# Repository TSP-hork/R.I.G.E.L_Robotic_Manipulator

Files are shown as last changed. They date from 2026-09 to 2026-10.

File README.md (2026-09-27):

# RIGEL — Robotic Interchangeable General-purpose Extensible Linkage

This repository is dedicated to the development of **RIGEL**, a high-performance, open-source modular robotic manipulator designed around an interchangeable and extensible architecture.

The goal of RIGEL is to create a versatile robotic platform where mechanical, electronic, and functional modules can be reconfigured, replaced, and extended without redesigning the entire system.

## Modular... what?

"Modular robotic platform" might sound like a fancy way of saying "a robot made from a bunch of parts." And, well... that's basically the idea.

Building and controlling a robotic arm usually requires deep programming skills and a complex understanding of the entire system, making most designs rigid and difficult to modify.

**RIGEL is my attempt to make that easier.**

The idea is to build the robot from interchangeable and extensible modules, so parts can be replaced, added, or reconfigured without redesigning the entire system.

And no, this is not a toy for grabbing cubes.

## What does "not a toy" mean?

A toy can grab something. A toy can rotate. This robot is designed to be a true industrial tool. It's designed to be precise and powerful enough to mill its own parts from aluminum, to weld, or to perform any task you can imagine.

The core idea is simple: This project provides a blueprint for anyone with common tools (like a 3D printer) and dedication to build an instrument capable of creating almost anything.

## How "good" is this cheap thing?

You might be thinking: "Okay, so you're making a cheap little arm and believe it can compete with a true, big, metal one? That's nonsense." And you are half right. This robot can't mill hardened steel or titanium. But does it need to?

What we all really need are strong, precise parts. We can't 3D-print metal, but this robot is designed to be precise enough to **mill aluminum**. This means you can use the first plastic robot to create the parts for its much stronger, metal successor. Sounds more realistic now, doesn't it?

But what about the "brains"? I've got you covered there too. This robot is being designed to run its control loop at **50 kHz**. This means it can react to a command in **20 microseconds** - the time from your signal to a change in the motor's current. And yes, it will work with almost any motor you want.

## Nice to meet you

I bet this sounds interesting. I just want to say hello, and I'm glad to see you here. This project started on May 27, 2025, and my goal is to build the first working prototype by next summer.

Maybe I'll make it, maybe I won't, but we'll find that out together. For now, you can find me here every Saturday. Let's get started!

## 05.07.26 Update "After a year"

Yeah, looking back, I wasn't sure what I was getting into at the start. I honestly thought I'd just tinker for a month and drop it, but here we are. Let's see what we've achieved!

I have finished the mechanics (I'd say they are 99% done). I also developed a 1kW motor driver—you can grab the Gerbers and order the boards for yourself(please note the non-commercial license below! sry for that). I've tested it and it works great, though I will personally be running it at 200W for this robot. I also wrote the FOC algorithm to control the motors.

I'll be continuing this journey, and I might change the name of the project soon. I really was here almost every Saturday (well, maybe not every single one, but I tried!).

A huge thank you to the two guys who starred my repo—it means a lot! I will keep going, we can do this! <Have a good day!> :>

## ⚖️ License

This project uses a **Dual-Licensing** model to protect both the software and the hardware designs.

*   **Software / Firmware:** All source code in this repository is licensed under the **GNU General Public License v3.0 (GPLv3)**. See the `LICENSE` file in the root directory for details.
*   **Hardware Designs:** All hardware files (Gerbers, Schematics, BOM, Pick and Place files, and 3D CAD models) located in the hardware/cad directories are licensed under the **Creative Commons Attribution-NonCommercial 4.0 International (CC BY-NC 4.0)** license. See the `LICENSE_HARDWARE.md` file for details.

**What this means for you:**
You are completely free to use, modify, and build the software and hardware for your own personal, educational, or hobby projects. However, **you may not use the hardware files for commercial purposes** (e.g., you cannot mass-produce the PCBs to sell them) without explicit permission.

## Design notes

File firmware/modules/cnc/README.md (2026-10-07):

# CNC Coordinator Module ESP32-S3

Standalone firmware module for coordinating a 3-axis robotic peripheral, a spindle variable-frequency drive, and a coolant/lubrication pump system.

## Architecture Principles

1. **Hardware Decoupling:**
   * The `Drivers/` layer handles chip-specific registers and startup for the ESP32-S3.
   * The `Core/` layer is portable and hardware-agnostic. All machine protocols, packet framing, and parsing logic are written in pure C without register dependencies.
2. **Centralized Application State (`main.c`):**
   * The main super-loop and master state machine live directly inside `main.c`, serving as the single source of truth for machine coordination, safety interlocks, and sequencing.
3. **WebSerial:**
   * The operator interface is a standalone local Web application (`src/ui/index.html`) running in any browser communicating directly over native USB Type-C via the WebSerial API.

## Project Structure

modules/cnc/
│
├── Makefile                      # Root build and flash script
├── CMakeLists.txt                # Tooling config for LSP, IDEs, and linters
├── README.md                     # Project documentation and quick-start guide
│
├── docs/                         # Specifications and hardware documentation
│   ├── pinout.md                 # ESP32-S3 pin assignments (UART, RS485, relays, USB-JTAG)
│   └── protocol.md               # 3-axis robot serial wire-protocol specification
│
└── src/
    ├── main.c                    # System entry point, master state machine & super-loop
    │
    ├── Core/                     # Hardware-independent machine logic
    │   ├── command_parser/       # Host command stream decoder
    │   │   ├── command_parser.c  # Ring-buffer parser and G-code/CLI tokenizer
    │   │   └── command_parser.h  # Command definitions and parser interface
    │   │
    │   ├── pump/                 # Coolant and lubrication subsystem
    │   │   ├── pump.c            # Relay timing logic and pressure/flow monitoring
    │   │   └── pump.h            # Pump control interface and status queries
    │   │
    │   ├── robot_interface/      # 3-axis robot communication driver
    │   │   ├── robot_interface.c # Frame serialization, timeout tracking & ACK handling
    │   │   └── robot_interface.h # Robot dispatch API and motion state flags
    │   │
    │   └── vfd/                  # Spindle inverter driver and Modbus RTU
    │       ├── vfd.c             # Modbus state machine, frequency scaling & current polling
    │       └── vfd.h             # VFD run/stop interface and register maps
    │
    ├── Drivers/                  # Hardware layer for ESP32-S3 
    │   ├── include/
    │   │   ├── bsp.h             # Hardware contract: exposed HAL interface for Core/
    │   │   └── esp32s3_regs.h    # Physical register addresses and bitmasks (GPIO, UART, WDT)
    │   └── src/
    │       ├── startup.S         # Reset vector, stack pointer setup & .bss zeroing
    │       ├── bsp_system.c      # Disabling MWDT/SWD watchdogs and PLL clock configuration
    │       ├── bsp_gpio.c        # Direct register pin-level read/write operations
    │       ├── bsp_uart.c        # Non-blocking UART FIFO handling and ring buffers
    │       └── bsp_timer.c       # Hardware timer tick generator
    │
    ├── ld/                       # Linker scripts
    │   └── esp32s3.ld            # SRAM and Flash memory region mappings
    │
    └── ui/                       # Operator control interface
        └── index.html            # Standalone WebSerial dashboard (inlined HTML, CSS & JS)
---

## Directory & Subsystem Overview

### `src/main.c`
The central commander of the system. Initializes the BSP layer and runs the primary non-blocking super-loop:
* Polls incoming USB packets and forwards them to `command_parser`.
* Evaluates safety interlocks (e.g., forbidding axis movement if spindle RPM or pump flow is unconfirmed).
* Dispatches motion commands to `robot_interface`.
* Polls `vfd` status and drives the master state machine (`IDLE`, `RUNNING`, `ERROR`, `PAUSED`).

### `src/Core/`
* **`command_parser/`**: Consumes raw byte streams from the host interface and converts them into structured command payloads.
* **`pump/`**: Controls the coolant/lubrication relay, manages start-up priming delays, and monitors pressure/flow switches.
* **`robot_interface/`**: Formats motion commands into the wire protocol expected by the peripheral 3-axis robot, handling timeouts and `ACK`/`BUSY` responses.
* **`vfd/`**: Calculates Modbus RTU CRC16 checksums, issues spindle run/stop commands, sets target frequency, and polls operating current/load.

### `src/Drivers/`
Contains all low-level hardware routines for the ESP32-S3:
* **`Drivers/include/bsp.h`**: The boundary contract exposing safe, non-blocking hardware functions (`bsp_uart_send`, `bsp_gpio_set`, `bsp_millis`) to `Core/` and `main.c`.
* **Hardware Drivers**: Register-level implementations of clock trees, watchdog timer disable sequences, UART FIFO handling, and interrupt vectors.

### `src/ld/`
Contains the linker script defining internal SRAM boundaries, vector tables, and Flash mappings.

### `src/ui/`
Self-contained HTML/JavaScript application. Runs locally on the host machine without web servers or Node.js. Connects directly to the board's native USB-Serial port to provide manual jogging, spindle overrides, and telemetry graphs.

---

## Toolchain & Prerequisites

ESP32-S3 utilizes the dual-core Xtensa LX7 architecture. Compilation requires the standalone Xtensa toolchain and OpenOCD:

1. **Toolchain:** Download the standalone `xtensa-esp32s3-elf` GCC toolchain release from Espressif's crosstool-NG repository and add its `/bin` directory to your `PATH` or set `PREFIX` in the `Makefile`.
2. **OpenOCD & Make :**
   ```bash
   # Ubuntu / Debian
   sudo apt update
   sudo apt install openocd make

   # Arch Linux
   sudo pacman -S openocd make
   ```

## Quick Start

### 1. Build the Binary
```bash
make
```
Executes a unified build with Link-Time Optimization `-flto`. Artifacts are written to `build/`.

### 2. Flash via Native USB-JTAG
ESP32-S3 features an on-chip USB-Serial/JTAG controller directly on the Type-C port (GPIO19/GPIO20):
```bash
make flash
```

### 3. Clean Build Artifacts
```bash
make clean
```

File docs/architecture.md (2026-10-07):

## Architecture.md

# Architecture of the RIGEL Robotic Manipulator

## Table of Contents

- [1. Overview](#1-overview)
- [2. Core Concept](#2-core-concept)
- [3. System Architecture](#3-system-architecture)
  - [3.1 System Block Diagram](#31-system-block-diagram)
  - [3.2 Data Flow: Control Loop](#32-data-flow-control-loop)
  - [3.3 Power Distribution](#33-power-distribution)
- [4. Electronics Architecture](#4-electronics-architecture)
  - [4.1 Motherboard](#41-motherboard)
  - [4.2 MCU: STM32H7A3](#42-mcu-stm32h7a3)
  - [4.3 FPGA: Lattice ECP5 (LFE5U-45F)](#43-fpga-lattice-ecp5-lfe5u-45f)
  - [4.4 MCU ↔ FPGA Communication](#44-mcu--fpga-communication)
  - [4.5 Power Blade (Axis Channel)](#45-power-blade-axis-channel)
  - [4.6 Technologist Module](#46-technologist-module)
  - [4.7 Input Power Board](#47-input-power-board)
- [5. Firmware Architecture](#5-firmware-architecture)
  - [5.1 FPGA Modules](#51-fpga-modules)
  - [5.2 MCU Firmware](#52-mcu-firmware)
  - [5.3 Control Loop Timing](#53-control-loop-timing)
- [6. Mechanical Architecture](#6-mechanical-architecture)
  - [6.1 Kinematic Configuration](#61-kinematic-configuration)
  - [6.2 Slew Drive (Rotary Support)](#62-slew-drive-rotary-support)
  - [6.3 Cabin](#63-cabin)
  - [6.4 Shoulder Module](#64-shoulder-module)
  - [6.5 Backpack (Motor + Reducer Mount)](#65-backpack-motor--reducer-mount)
  - [6.6 Balanced Cycloidal Reducer](#66-balanced-cycloidal-reducer)
  - [6.7 Base](#67-base)
- [7. The Technologist Module: Design Philosophy](#7-the-technologist-module-design-philosophy)
- [8. Design Principles](#8-design-principles)
- [9. Target Specifications](#9-target-specifications)
- [10. Current Status and Roadmap](#10-current-status-and-roadmap)

---

## 1. Overview

The RIGEL Robotic Manipulator is a fast, precise,
and affordable robotic arm designed for simple assembly, easy operation,
and tool-agnostic deployment. It is built from four electronic subsystems:
an Input Power Board, a Motherboard, hot-swappable Power Blades, and a
hot-swappable Technologist Module.

The robot is designed so that any person with a 3D printer and basic tools
can build an instrument capable of precise spatial positioning — precise
enough to mill aluminum and manufacture parts for a stronger, metal version
of itself.

## 2. Core Concept

The central idea behind RIGEL is the separation of concerns:

- **The Robot** is a precision positioning tool. It moves a point in space
  from A to B. It is a black box with a simple API.
- **The Technologist Module** defines *what to do*. It controls the tool,
  sends high-level commands, and can be swapped in seconds.
- **The Power Blades** drive the motors. They are hot-swappable cards that
  plug into the motherboard via a standard PCIe physical connector.

This separation means that switching from milling to welding requires only
swapping the Technologist Module and the tool — not reprogramming the robot.

## 3. System Architecture

### 3.1 System Block Diagram

```
[PSU 8-60V] ──→ [Input Power Board*] ──→ [MOTHERBOARD]
                                              │
                 ┌────────────┬───────────────┼───────────────┬────────────┐
                 │            │               │               │            │
            [Blade 1]   [Blade 2]   ...  [Blade 6]   [Technologist Module]
                 │            │               │               │
           [Motor+Enc]  [Motor+Enc]     [Motor+Enc]      [Tool/End Effector]

Inside the Motherboard:
┌─────────────────────────────────────────────────────────────────────┐
│                                                                     │
│   [FPGA: Lattice ECP5] ←── data bus ──→ [MCU: STM32H7A3]          │
│        │                                      │                     │
│        ├─ PWM signals      → Blade PCIe slots  ├─ FOC algorithm     │
│        ├─ Encoder data     ← Blade PCIe slots  ├─ Inverse kinematics│
│        ├─ SPI (ADC data)   ← Blade PCIe slots  ├─ API ↔ Tech Module│
│        ├─ Hardware dead-time protection         ├─ State machine     │
│        └─ Hardware clock sync (for clustering)  └─ Trajectory plan  │
│                                                                     │
│   [PCIe x8 Slots × 6]              [PCIe Slot × 1: Tech Module]   │
│                                                                     │
└─────────────────────────────────────────────────────────────────────┘

* Input Power Board is not implemented in the prototype.
  The prototype is powered directly from a 24V PSU.
```

### 3.2 Data Flow: Control Loop

Every control cycle (target: 20 µs / 50 kHz):

```
Step 1: FPGA triggers ADC conversion on the Blade
            │
Step 2: STM32G431 (on Blade) samples 3 phase currents
            │
Step 3: ADC data is sent via SPI to the FPGA          ← ~400 ns
            │
Step 4: FPGA decodes quadrature encoders (parallel)   ← 1-2 clock cycles
            │
Step 5: FPGA writes currents + positions directly
        into MCU registers (via data bus)              ← no CPU overhead
            │
Step 6: MCU (STM32H7) executes:
        - Clarke/Park transforms
        - PID current regulators (FOC)
        - Inverse kinematics
        - Trajectory interpolation
            │
Step 7: MCU writes PWM duty cycles directly
        into FPGA registers (via data bus)             ← no CPU overhead
            │
Step 8: FPGA generates 6 PWM signals with
        hardware dead-time insertion
            │
Step 9: PWM signals reach gate drivers on the Blade
            │
Step 10: Motor responds. Cycle repeats.
```

Key architectural advantage: Steps 3, 4, 5, and 7 happen with **zero CPU
involvement**. The FPGA handles all signal acquisition, decoding, and
routing in parallel, while the MCU focuses purely on math. Adding more
sensors or encoders does not increase MCU load or introduce jitter.

> **Current prototype status:** The full control chain has been validated
> at 20 kHz using development boards (Tang Nano 9K as FPGA, STM32H7 Nucleo
> as MCU) connected via SPI. The FPGA acts as SPI master and triggers the
> MCU via EXTI interrupt on each frame. The target architecture (direct
> register bus, 50 kHz) will be implemented on the motherboard.

### 3.3 Power Distribution

```
[External PSU: 8-60V DC]
        │
[Input Power Board*] ── filtering, protection, regulation
        │
[Motherboard Power Rail]
        ├──→ Blade slots (Vbus passthrough to motor drivers)
        ├──→ 12V DC/DC → FPGA, gate driver logic supply
        ├──→ 5V  DC/DC → MCU, digital logic
        ├──→ 3.3V LDO  → MCU core, FPGA I/O banks
        └──→ Technologist Module slot (5V or 3.3V selectable)

Each Blade has its own on-board power regulation:
[Vbus from Motherboard]
        ├──→ 12V DC/DC (TPS54360B) → gate driver bootstrap
        ├──→ 5V  LDO  (LM7805)    → STM32G431, RS-485
        └──→ 3.3V LDO (TLV1117)   → logic, analog reference

* Not implemented in prototype. Robot is powered directly at 24V.
```

---

## 4. Electronics Architecture

### 4.1 Motherboard

The Motherboard is the central hub. It hosts:

- **MCU:** STM32H7A3 — the brain of the robot.
- **FPGA:** Lattice ECP5 (LFE5U-45F) — the signal engine.
- **PCIe x8 slots** (×6) for Power Blades.
- **PCIe x8 slot** (×1) for the Technologist Module.
- **Power input terminals** from the Input Power Board (or directly from PSU).
- **Clock synchronization output** on the Technologist Module connector.

> **Important:** The PCIe x8 connector (98-pin, part: 10018784-10202TLF) is
> used **only as a physical/mechanical connector**. The PCIe protocol is
> **not** used. The pinout is custom-defined for this project.

### 4.2 MCU: STM32H7A3

The MCU is the high-level computational center. Its responsibilities:

- **FOC (Field-Oriented Control)** — Clarke/Park transforms, PID regulators.
- **Inverse kinematics** — converting Cartesian coordinates to joint angles.
- **Technologist Module API** — receiving high-level commands (e.g., "move to
  point X,Y,Z") and decomposing them into per-axis motor control tasks.
- **Trajectory planning** — interpolation, acceleration profiles.
- **System state machine** — initialization, calibration, operation, error
  handling.

The MCU does **not** directly read encoders or generate PWM. All signal I/O
is handled by the FPGA and mapped into MCU memory via the data bus.

### 4.3 FPGA: Lattice ECP5 (LFE5U-45F)

The FPGA is the real-time signal engine. Its responsibilities:

- **PWM generation** — center-aligned PWM at the duty cycle specified by
  the MCU. All channels are generated in parallel.
- **Hardware dead-time insertion** — prevents shoot-through on half-bridges.
  This is a critical safety function implemented in hardware, not software.
- **Quadrature encoder decoding** — reads and decodes encoder signals for
  all axes simultaneously, in parallel, with glitch filtering.
- **ADC data reception** — receives SPI data from the STM32G431 ADC on each
  Blade and places it directly into MCU-accessible registers.
- **Hardware clock synchronization** — generates a synchronization clock
  signal for multi-robot clustering. This clock is routed to the
  Technologist Module connector.

The FPGA communicates with the MCU via a direct data bus that allows
register-level read/write access in both directions.

### 4.4 MCU ↔ FPGA Communication

The MCU and FPGA are connected via a parallel data bus that enables direct
register access:

- The **MCU writes** PWM duty cycles and frequencies directly into FPGA
  registers. No serialization, no protocol overhead.
- The **FPGA writes** encoder positions and ADC values directly into
  MCU-accessible memory. No interrupt handling, no polling.

This architecture eliminates the communication bottleneck that typically
limits multi-axis servo systems. Adding a new axis (a new Blade with
motor and encoders) does not increase the MCU's I/O workload — it only
adds more math to compute.

> The specific bus interface (FMC, FSMC, or custom parallel bus) will be
> finalized during motherboard development.

### 4.5 Power Blade (Axis Channel)

The Power Blade is a modular motor driver on a PCB with a PCIe x8 edge
connector. Each Blade drives one motor (one axis).

**Specifications:**

| Parameter | Value |
|---|---|
| Connector | PCIe x8 (98-pin, physical only) |
| Rated power | 150–300 W (continuous) |
| Peak power (by design) | 1200 W |
| Switching frequency | 50 kHz |
| MOSFETs | NTMFS3D5N08XT1G (80V, 3mΩ, 23nC)  |
| Gate drivers | IRS21867S (4A peak, 600V) |
| Current sensing | INA240A1DR (×3, 20 V/V gain) |
| Shunt resistors | 5mΩ, 3W, 1% |
| On-board ADC | STM32G431RBT6 |
| Communication to FPGA | RS-485 (SN65HVD75DR), SPI |

**Why STM32G431 as ADC?**

A dedicated ADC IC would be cheaper per channel but would require more
external circuitry. The STM32G431 provides three 12-bit ADCs with hardware
synchronization, all in a single $1.5 package. It also runs at 170 MHz,
which allows it to handle the ADC-to-SPI pipeline with a latency of
approximately 400 ns and zero CPU intervention on the main MCU. In the
future, the G431 will also monitor Blade health (temperature, voltage,
fault conditions).

**Thermal note:** At the nominal operating point (24V, 4A), total
conduction losses across all 6 MOSFETs are under 0.3W. Even at the
maximum design current (10A), losses remain under 3W. The SuperSO8
package dissipates this without a heatsink. Active cooling is not required.

> Full component list and selection rationale: see `hardware/docs/components.md`

### 4.6 Technologist Module

The Technologist Module is the user-facing control interface. It plugs into
a dedicated PCIe slot on the Motherboard and communicates with the MCU via
a minimal interface:

```
Pin allocation (conceptual):
- Power:  VCC (5V or 3.3V)
- Ground: GND
- Data:   TX (commands from module → MCU)
- Data:   RX (feedback from MCU → module)
- Clock:  SYNC (hardware synchronization clock from FPGA)

```

From the Technologist Module's perspective, the entire robot is a **black box** with a simple API:

- Send: `MOVE_TO(x, y, z, speed)`
- Send: `SET_JOINT(axis, angle)`
- Receive: `POSITION(x, y, z)`
- Receive: `STATUS(state, error_code)`

The Technologist Module has **no access** to the internal control loop,
FOC parameters, or motor-level commands. It cannot modify the closed-loop
control algorithms.

The module is also directly connected to the end-effector (tool). It
controls the tool independently of the robot's positioning system.

**Key design intent:** Swapping the Technologist Module changes the robot's
task. A milling module commands precise paths and controls a spindle.
A welding module commands different paths and controls a welder. The robot
itself does not change. This is the "hot-swap" in HSPS.

> The physical communication protocol (UART, SPI, or custom) and the
> command format will be finalized during Technologist Module development.

### 4.7 Input Power Board

The Input Power Board sits between the external power supply and the
Motherboard. Its purpose is to protect and condition the incoming power:

- Input voltage filtering (EMI suppression)
- Overvoltage and overcurrent protection (disconnect on fault)
- Voltage regulation/stabilization for noisy or unstable sources
- Accepted input range: 8V to 60V DC

> **Not implemented in the prototype.** The prototype connects a regulated
> 24V PSU directly to the Motherboard. The Input Power Board will be
> developed for the production version after the core concept is validated.

---

## 5. Firmware Architecture

### 5.1 FPGA Modules

The FPGA design is written in SystemVerilog and consists of independent,
parallel modules:

| Module | Function |
|---|---|
| `system_storage` | Central register file (CSR). Shared memory between  |
| | FPGA and MCU for all axis data. |
| `pwm_generator` | Center-aligned PWM generation for FOC. |
| `deadtime` | Hardware dead-time insertion. Prevents shoot-through|
| | on half-bridge MOSFETs. Cannot be bypassed by SW.  |
| `quadrature_decoder`  | Decodes ABZ encoder signals with glitch filtering. |
| `spi_master` | Configurable-width SPI master for MCU and ADC |
| | communication. |
| `top` | Top-level integration: 3-axis instantiation, |
| | exchange FSM, tick timer. |

All modules run in parallel. Adding a new axis means instantiating another
set of modules — no impact on existing axes' timing.

### 5.2 MCU Firmware

> **Status:** The FOC algorithm is implemented and validated at 20 kHz on
> development boards (Tang Nano 9K + STM32H7 Nucleo). The target frequency
> of 50 kHz will be achieved on the final motherboard with FMC bus.

The MCU firmware runs on the STM32H7A3 and implements:

- **FOC (Field-Oriented Control):** Clarke/Park transforms, PI current
  regulators in the d-q reference frame. **Implemented and tested.**
- **SVPWM modulation:** Space-vector PWM with min-max injection for
  optimal DC bus utilization. **Implemented and tested.**
- **Position/velocity control loop:** Outer loop using encoder feedback.
  *Planned.*
- **Inverse kinematics solver:** Converts Cartesian commands from the
  Technologist Module into joint-space targets. *Planned.*
- **Technologist Module communication handler:** Parses incoming commands,
  queues them (FIFO), executes in order, sends back position feedback.
  *Planned.*
- **State machine:** Manages robot states (boot → calibration → idle →
  moving → error → emergency stop). *Planned.*

### 5.3 Control Loop Timing

Target control loop period: **20 µs (50 kHz)**.

```
Budget breakdown (target):

ADC sampling + SPI transfer:     ~0.5 µs
FPGA encoder decoding:           ~0.02 µs (1-2 FPGA clock cycles)
FPGA → MCU register write:       ~0.1 µs
MCU: FOC computation:            ~5-10 µs (estimated)
MCU → FPGA register write:       ~0.1 µs
FPGA PWM update:                 ~0.02 µs
────────────────────────────────────────────
Total estimated:                 ~6-11 µs
Margin:                          ~9-14 µs
```

This timing budget is achievable because signal acquisition (steps 1-3)
and signal generation (step 6) are handled entirely by the FPGA in
parallel with MCU computation. The MCU only performs math.

**Why this matters for precision:**

Two encoders per axis (one on the motor shaft, one on the output after
the reducer) are read simultaneously by the FPGA. At 50 kHz, the robot
corrects its position every 20 µs. This high update rate, combined with
dual-encoder feedback, compensates for reducer backlash and mechanical
imperfections in software — reducing the need for expensive, high-precision
mechanical components.

Scaling to 100 kHz (10 µs) is architecturally possible by using a faster
MCU or offloading parts of the FOC computation to the FPGA, with no
changes to the system architecture.

---

## 6. Mechanical Architecture

### 6.1 Kinematic Configuration

The robot is a serial-link articulated manipulator. The prototype
implements 3 axes (for concept validation), with the architecture designed
to scale to 6 axes.

The mechanical structure consists of modular, standardized elements
connected via a 20mm shaft interface. Each joint is driven by a BLDC motor
through a balanced cycloidal reducer and a belt final stage.

```
[Base] → [Slew Drive: Axis 1 (rotation)]
              → [Cabin]
                   → [Shoulder Module: Axis 2 (pitch)]
                        → [Shoulder Module: Axis 3 (pitch)]
                             → [End Effector / Tool]
```

### 6.2 Slew Drive (Rotary Support)

The slew drive provides Axis 1 rotation. It consists of three 3D-printed
parts:

- **Stator:** A circular base with bolt holes for mounting to the base.
  It has an outer wall and an inner wall forming a rectangular channel
  (raceway) in which bearings ride.
- **Rotor:** A ring that fits inside the stator bore with finger
  protrusions around its circumference. Bearings are pressed onto the
  fingers and ride in the stator channel.
- **Cover:** A ring that bolts onto the stator, closing the channel and
  constraining the bearings axially.

The assembly creates a rigid constraint that allows free rotation while
preventing tilting (nodding) of the robot. The stator raceway is expected
to wear over time with 3D-printed materials and will be reinforced in
future iterations.

### 6.3 Cabin

The cabin connects the slew drive (Axis 1) to the first shoulder joint
(Axis 2). Its design is inspired by industrial heavy equipment
(excavators), where the rotation axis is offset from the arm attachment
point:

- The arm attaches to one side via two bearing ears forming a U-shaped
  yoke.
- The opposite side houses the motor and reducer for Axis 2, acting as a
  counterweight.
- This layout eliminates the tuning-fork resonance effect, increases
  structural rigidity, and partially balances the arm when fully extended.

### 6.4 Shoulder Module

The shoulder module is a standardized structural link. It consists of:

- **Base end:** Two ears that clamp onto a 20mm shaft using hex nuts and
  bolts (6 bolt points per ear), providing a rigid connection.
- **Truss section:** A lightweight lattice/truss structure for
  stiffness-to-weight optimization. Walls are 5mm+ PETG with 100% infill.
  Four 8mm steel rods run inside the truss as internal reinforcement,
  creating a composite structure with rigidity comparable to aluminum
  tube of similar cross-section.
- **Head end:** A U-shaped yoke with bearing bores for the next joint's
  shaft, plus mounting points for the Backpack module.

Multiple shoulder modules can be chained using the same 20mm shaft
interface to extend the arm. The prototype uses a long module and a short
module.

### 6.5 Backpack (Motor + Reducer Mount)

The Backpack is a box-shaped module that mounts underneath the shoulder
module's head, attaching to the same interface used for the yoke. It
serves multiple purposes:

- Houses the motor and reducer for the next joint.
- Stiffens the yoke ears, eliminating tuning-fork resonance.
- Shifts the center of mass closer to the previous joint axis, reducing
  dynamic loads.
- Aligns the reducer output shaft and belt drive with the joint axis.

### 6.6 Balanced Cycloidal Reducer

The reducer is a custom-designed, 3D-printable balanced cycloidal drive.

**Specifications:**

| Parameter | Value |
|---|---|
| Reduction per stage | 10:1 |
| Stages in prototype | 2 (= 100:1) |
| Maximum stages (by volume) | 3 (= 1000:1) |
| Belt final stage | 1:3 |
| Total reduction (prototype)  | 300:1 |
| Form factor | Fits in the palm of a hand |

The high reduction ratio is necessary because the design uses high-RPM,
low-torque BLDC motors. The architecture allows any motor to be used — if
high-torque motors are chosen, the reducer can be simplified or removed.

**Key discovery during development:**

For a rigidly connected, balanced (counter-rotating) dual-disc cycloidal
drive, the standard clearance formula does not apply. The correct formula
for the hole diameter in the cycloidal discs is:

```
Hole_Diameter = Pin_Diameter + (4 × Eccentricity)
```

This is **double** the clearance required for single-disc or independently
suspended designs. This finding was validated through physical testing.

> Detailed development history and the reasoning behind this formula can
> be found in the [Development Log](DEVLOG.md).

### 6.7 Base

The prototype base is a heavy concrete block. An earlier plan to 3D-print
a plastic base was abandoned because it would have required over 2 kg of
plastic while still being too light to provide adequate stability. The
concrete block is cheap, heavy, and meets all requirements.

---

## 7. The Technologist Module: Design Philosophy

The Technologist Module is the most architecturally significant part of
this project. It is what differentiates this robot from others at a
fundamental level.

**The problem it solves:**

Most robotic arms tightly couple the control software with the robot
hardware. Changing the robot's task means rewriting code, reconfiguring
the controller, and often physically modifying the system. This makes
robots expensive to deploy and inflexible in practice.

**The solution:**

The Technologist Module separates *what the robot does* from *how the
robot moves*. The robot's internal control system (FOC, kinematics,
trajectory planning) is a sealed black box. The Technologist Module
communicates with this box through a simple, high-level API.

**What this enables:**

- **Tool independence:** The module controls the tool directly. The robot
  only positions it. Swapping tools means swapping modules.
- **Protocol independence:** The module can communicate with the outside
  world via any interface — Ethernet, EtherCAT, USB, CAN, Wi-Fi, or
  simply execute a pre-programmed sequence from flash memory. The robot
  does not care.
- **Rapid deployment:** A new application requires designing only a small
  PCB with a microcontroller and a PCIe connector. The robot, its
  firmware, and its calibration remain untouched.
- **Clustering:** Multiple robots can be synchronized via the hardware
  clock signal exposed on the Technologist Module connector. This enables
  multi-robot cooperative tasks (e.g., holding a workpiece with one robot
  while another machines it).

**Physical form:**

A small PCB with a microcontroller, a PCIe edge connector, and
(optionally) an external communication interface. It plugs into the
dedicated slot on the Motherboard and is powered by it (5V or 3.3V).

---

## 8. Design Principles

1. **The robot is a black box.** It moves a point in space from A to B.
   Everything inside stays inside. Everything outside stays outside.

2. **Modularity over monolith.** Every subsystem — mechanical and
   electronic — must be independently testable, replaceable, and
   repairable. A Blade swap should take seconds. A shoulder module swap
   should take minutes.

3. **Precision through speed, not mechanics.** Industrial robots achieve
   precision through expensive, ultra-tight-tolerance mechanical
   components. This robot achieves precision through a fast control loop
   (50 kHz) with dual-encoder feedback, correcting mechanical
   imperfections 50,000 times per second.

4. **Infinite scalability (as a goal).** The architecture should allow
   adding more axes, more sensors, and more robots without fundamental
   redesign. The FPGA's parallel nature makes this feasible for I/O.
   The standardized mechanical interfaces make this feasible for
   structure.

5. **Power agnosticism.** The robot should accept any DC power source
   from 8V to 60V. If it can be deployed anywhere, it should be powered
   from anywhere.

6. **Accessibility.** The robot must be buildable by anyone with a 3D
   printer and common tools. The BOM cost should be comparable to a
   power tool, not an automobile.

7. **Reusability.** Like good code, no part of the robot should be
   single-purpose. The shoulder module is the same for every joint. The
   Blade is the same for every axis. The reducer is the same at every
   stage.

8. **Motor agnosticism.** The control system must work with any BLDC
   motor. The system should be able to characterize an unknown motor
   and configure itself accordingly.

9. **The tool defines the task, not the robot.** Swapping the
   Technologist Module and the end-effector changes the robot's purpose.
   Today it mills. Tomorrow it welds. The robot itself does not change.

10. **Mechanics is necessary but not primary.** We cannot build a robot
    from sticks, but we also must not rely solely on mechanical precision.
    A $50,000 harmonic drive on a poorly controlled system is still a
    poorly controlled system.

---

## 9. Target Specifications

| Parameter | Prototype (3-axis) | Target (6-axis) |
|---|---|---|
| Degrees of freedom | 3 | 6 |
| Control loop frequency | 50 kHz (20 µs) | 50–100 kHz |
| Input voltage | 24V DC | 8–60V DC |
| Current per axis (nominal) | 4 A | configurable |
| Current per axis (peak) | 10 A | configurable |
| Power per axis (nominal) | ~100 W | ~150–300 W |
| Encoder resolution | TBD | TBD |
| Encoders per axis | 2 (motor + output) | 2 (motor + output) |
| Reducer ratio | 300:1 (100:1 + 1:3) | up to 1000:1 + belt  |
| Motor type | BLDC (any) | BLDC (any) |
| Positioning accuracy (target) | < 0.1 mm (with cal.)  | < 0.05 mm (with cal.)|
| Payload | TBD | TBD |
| Reach | TBD | TBD |
| Robot mass (estimated) | TBD | TBD |
| Electronics BOM (3-axis) | ~$80–120 (estimated)  | TBD |
| Frame material (prototype) | PETG (3D-printed) | Aluminum (milled) |
| Blade swap time | Seconds | Seconds |
| Technologist Module swap time | Seconds | Seconds |

---

## 10. Current Status and Roadmap

> For detailed week-by-week progress, see the [Development Log](DEVLOG.md).

### Completed

- [x] Core mechanical design (3-axis CAD)
- [x] Balanced cycloidal reducer (designed, printed, assembled, tested)
- [x] Shoulder modules (printed and assembled)
- [x] Slew drive (printed and assembled)
- [x] Power Blade schematic design
- [x] Power Blade PCB layout and routing
- [x] Component simulations (DC/DC, current amplifier, half-bridge)
- [x] FPGA core (PWM generator, dead-time, encoder decoder, CSR, SPI master)
- [x] ADC-to-SPI pipeline on STM32G431 (~400 ns latency)
- [x] Gerber/BOM/CPL files generated
- [x] PCBs ordered and received
- [x] Power Blade power-on test (all voltages verified)
- [x] FOC algorithm implementation on STM32H7 (Clarke, Park, PI, SVPWM)
- [x] Full control chain validated: ADC → FPGA → MCU → FPGA → motor (20 kHz)

### In Progress

- [ ] Remaining mechanical assembly (shoulder fitting, belt tensioning)
- [ ] Motor spinning on Power Blade (transitioning from dev boards)
- [ ] Motherboard schematic design

### Future

- [ ] Motherboard PCB design
- [ ] Technologist Module prototype
- [ ] Input Power Board
- [ ] Position/velocity servo loop
- [ ] Inverse kinematics
- [ ] Multi-robot clustering
- [ ] Calibration system (reference flat surface)
- [ ] Aluminum version (self-manufactured)

---

*Project started: May 27, 2025*
*This document reflects the architecture as of the prototype development phase.*
*For component details, see [components.md](hardware/docs/components.md).*
*For development history, see [DEVLOG.md](DEVLOG.md).*

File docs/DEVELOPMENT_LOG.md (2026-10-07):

# 2025-08-13: The Project is Public!

## Milestone
Today, I've made the repository public and started this development log. This marks the official start of the public phase of the project.

## Current Status
The majority of the conceptual CAD work for the core 3-axis mechanics is complete (around the 90% mark). I've been so focused on design iterations and preparing for the first printing tests that I haven't committed the CAD files to the repository yet.

## Next Steps
My immediate goal is to clean up the models and push the complete set of F3D/STEP files to the /cad directory by this Saturday (August 16th).

## Comment
If someone rly see this **hey,have a nice day! :>** i hope what i make that to this saturday cuz with this i need to start making PCB its little scary but we need this to 50 kHz. <Cya> 

## 2025-08-24: Stage II Begins - Electronics & First Working Prototype!

### Milestone
This weekend marks the official start of the electronics development phase. The core mechanical and electronic architectures are now finalized. Most importantly, the first PLA prototype of the 10:1 reducer module was printed, assembled, and **it works flawlessly!**

### Current Status
Following the successful test of the 10:1 reducer, I will be uploading its final STL files to the /manufacturingdirectory. The PDF overview of the electronics architecture is now also available in/hardware/docs.

The initial assembly of the reducer revealed a critical kinematic conflict: the drive did not work. After analysis, I identified a mistake in the clearance calculation for the output flange fingers. The holes in the cycloidal discs were recalculated and enlarged, which completely solved the issue.

### Next Steps
The primary focus now shifts to designing the **Power Blade** electronics. In parallel, I will continue printing and testing the complete mechanical assembly. I'm considering creating a **Telegram channel** to post real-time development updates, including videos and failures. Let me know if you'd be interested!

### Comment & Key Discovery
I have to admit, when the first reducer assembly seized up, I was worried about the entire design. But after thinking through the kinematics, I realized a fundamental principle for balanced cycloidal drives with a rigid output cage.

The standard formula for hole clearance, Hole_Diameter = Pin_Diameter + (2 * Eccentricity), is only valid for a single-disc or independently suspended dual-disc setup.

For a **rigidly connected, balanced (counter-rotating) dual-disc setup**, the required clearance is doubled. The correct formula is:

**Hole_Diameter = Pin_Diameter + (4 * Eccentricity)**

This was a scary realization, as it required making the holes in my very compact reducer significantly larger. However, the design had enough material to accommodate this. After reprinting the discs with the corrected hole diameter, the reducer works perfectly. This is a crucial finding for anyone building this type of drive.

This week, I will try to develop the full Power Blade schematic. And again i write this at midnight... <Cya guys, sleep well>

## 2025-09-02: Little sick but with power blade architecture!

### Milestone
Power blade architecture is DONE! The short shoulder module is printed.

### Current Status
The architecture was a little easy for me because I had been thinking about it for two weeks, so I just sat down and made it. But with printing, I am continuing my war with the 3D printer. It just stopped in the middle of the night while I slept and ruined about 90% of the print. I need to start again and buy more plastic, but the printer is far from me, so I will restart printing next weekend ":/"

### Next Steps
The next step is to totally finish the blade's schematic and start to test it in SPICE programs. In parallel, I need to pick components for the blade. And of course, printing, printing, printing....

### Comment & Key Discovery
All week I was sick, and after work, I just lay in bed and thought about how much I needed to do but couldn't. BUT on the weekend, I was fine and finished the architecture. That was a victory! -^-

## 2025-09-07: POWER BLADE SCHEME IS 90% DONE!!

### Milestone
Power blade scheme is 90% done. Printing new shoulder module.

### Current Status
Updated settings for 3D printer and start printing part of shoulder module again. Ears printed and i think it okay. Today i buyed shafts and other steel staff they gonna come like... 2-3 weeks... I added datasheets and file "components" for (You won't believe it :> ) components for boards and add all components for axis channel. My win today is scheme power blade done on 90% its just need to make footprints and past. Ye i needed to test power blade today in spice program but without footprints its unreal and i dont make it not proud for that..

### Next Steps
The next step is stay same test and finishing scheme and after i can make pcb.

### Comment & Key Discovery
**DAY NOT OVER WHILE I DONT LAY!** 
Weekend again was hard cuz i have no time for help familly and no time for this robotic arm, but i sit here and now is totaly early morning i writing this and go to sleep. Printer is printing night going to over. on this week i will be study and work and free time on week is die. Have a good night guys <cya>

## 2025-09-14: Real-World Assembly & Design Evolution

### Milestone
The first full two-stage reducer prototype was assembled and tested. While encountering critical issues, the tests successfully validated the core kinematic design and led to a significantly improved and more robust architecture.

### Current Status & Key Discoveries
This weekend was dedicated to the first physical assembly of the two-stage balanced cycloidal reducer. The test was a partial success:

    The Good: The core mechanism works. When assembled, all parts fit, and the kinematics are correct — the drive rotates and provides reduction. The new, longer stator pins, when press-fitted (with a hammer), provide excellent structural rigidity without interfering with the cycloidal discs' motion.

    The Bad (Problems Found):

        Structural Failure: The bottom wall of the main reducer shaft proved to be too thin. It cracked and crumbled under the stress of assembly (e.g., inserting an M8 nut).

        Stator Pin Instability: The stator pins were not sufficiently constrained and could be dislodged, leading to mechanism failure.

    The Ugly (Resource Loss): Lost two major prints (~800g of PETG and ~40 hours of print time) this past week due to a corrupted SD card file and suboptimal print settings that caused delamination. This is a painful but valuable lesson in process reliability.

### Design Evolution (The Solutions)
Based on the test results, I've developed a new, more robust design:

    Motor-to-Reducer Coupling: The initial concept for the input shaft was flawed. The final design will be: a pneumatic collet fitting (with metric M6 thread) screwed into a heat-set brass insert in the 3D-printed reducer shaft. The entire assembly will be locked by a transverse pin ("the nail") secured with a retaining ring. This provides a robust, balanced, and modular interface.

    Stator Assembly: The stator pin instability will be solved by:

        Closing the open holes in the stator plates.

        Adding an intermediate stator plate between the two stages for added support.

        Increasing the contact surface area between the stators and the pins.

The CAD models will be updated with these improvements next week. The only potential delay is sourcing the non-standard M6 heat-set inserts.

### Next Steps & Plan Adjustment
The initial plan to start the PCB layout this week is postponed. The unexpected but critical mechanical redesign takes priority.

    This Week (Evenings): Continue with the Power Blade schematic design. The goal is to have it 100% complete by the next weekend.

    Next Weekend: Finalize the mechanical redesign in CAD and begin printing the new, improved parts.

    Documentation: I will update the repo with the final printer settings, add component libraries, etc.

### Comment
This was the first major "slip" in the schedule due to the demanding university timetable and unforeseen design flaws. I had planned to be working on the schematic this weekend but spent almost all of it on mechanical assembly and problem-solving. This is frustrating but also incredibly productive. The design is now an order of magnitude better.

In same situations i remember this quote:

    You know, the world isn't run by the laws written on paper. It's run by people. Some according to laws, others not. It depends on each individual how his world will be, what he will make of it... I dreamed of fortunes, cars, freedom, women, respect... I got it all more or less, but with it came prison, constant fear, and the blood of my comrades.

    — Mafia: The City of Lost Heaven

But unlike that story, **we don't give up so easily.** There is more to come and rest will be after revolution in robots :)

Thanks for following along. <Cya guys!>

## 2025-09-15: little steps 

### Milestone
I finished schematics for components everything except `ADC` and add `PRINTER.md` to docs 

### Comment

**I think for little commits on week i will be use milestones and comments, cuz i cant doing many work for my robot and u can see other information like next steps u can see upper.**

For today i maked 2 scheme of components DC/DC and LDO 5V and i bought components for connect reducer shaft and motor shaft. after they come i assembly reducers and test it and i think now that will be immortal connection ~~(sounds like joke)~~ but anyway we can see it later. For other i add my config for 3d printer to `docs/guides/PRINTER.md` u can check what settings i using for printing mb its can help u :)

## 2025-09-16: schematics for components are completed !!!

### Milestone
I completed scheme for STM32G4 and add all schematics to repository !!!!!

### Comment
So so so that was too long for one component but all functions for every pin from datasheet in schem and that now have footprint. 
I change MC cuz i little mistake with price for `STM32G474CEU6` u can read about that to `hardware/docs/components.md`. time to sleep.. <Cya>

# 2025-09-23: Principle scheme is complete!

## Milestone
Completed the schematic; simulations and printing are underway

## Current Status
I completed the schematic, started printing the second part of the shoulder module, and successfully assembled the shoulder module on the shaft. I also started the simulation using the INA240 in LTspice

## Next Steps
Finish simulations and start PCB design and create a Telegram channel

## Comment
This weekend was tough: I started around 9:00 PM and worked until about 4:30 AM on Saturday and 5:00 AM on Sunday. On Monday I worked and fixed the schematic — the pin headers for the joke turned out to be harder than 60% of the circuit design. I spent 4 hours figuring out how to use PCI — it's just a connector I can use for the board. Before that I considered a mezzanine connector but couldn't find one compatible with my board that didn't cost almost as much as the whole board with all components. Now we're using PCI at a reasonable price. During the week I will create a Telegram channel to document activity like videos and fails, since using Git for that is inconvenient; I'll be there all week.

# 2025-09-23: Simulation INA240 are complete!!!!

### Milestone
* Add all spice schematics for axis channel blade
* Create directory `simulatons` 
* Made 4 simulations for `INA240` amplifier.
* Made telegram channel 

### Comment
All week i working and afer work i just lay and its all what i did and that will be true if i was a just good worker who woudnt sleep tomorrow, for that after work maked simulations and learn LTspice...khm.. i working in this program before but with simple simulations and now i tryed be serios so today we have complete simulation for first component! <Good night~>

# 2025-09-28: ALL SIMULATIONS COMPLETE. STARTING PCB!!!!

## Milestone
Completed all simulations and the final schematic for the Axis Channel. Remodeled the head of the shoulder module and the shaft for the 10:1 reducer.

## Current Status
- **Simulations:** Successfully completed and verified the DC/DC, Current Amplifier, and Half-Bridge circuits.
- **Documentation:** Created a guide on how to import SPICE models.
- **CAD:** Remodeled the shoulder modules and the reducer shaft. Started printing the main shoulder part.

## Next Steps
- **Start the PCB layout** for the Axis Channel blade.
- **Finish** the CAD models for the reducer and shoulder assembly.

## Comment

I thought the simulations would be the easy part - just load models and run. The DC/DC simulation, on the other hand, was done in 30 minutes. The half-bridge, however, took an entire day just to get it to work at all.

In the end, I got the basic simulation running and saw the square waves, which is a success. Honestly, I hoped to simulate a real "hell" scenario for it with all the parasitics and protections, but that's a project in itself, and I just don't have that much time to spend only on simulations.

So I made a pragmatic engineering decision: I based the final schematic on proven reference designs from datasheets and application notes, using LTspice just for a basic "does it switch?" sanity check, without the deep, "hard tests". It's a calculated risk, but a necessary one to move forward.

Now, I continue my war with the reducer models. It needs so many iterations of printing parts, which is not easy when I can only print 2 days a week. I spent most of this weekend just modeling because I messed up the sizes for the main shaft bearing... I don't know how it happened, but it is what it is.

So, time is again not on my side. Looks like another night of 4 hours of sleep... Thanks for your attention, have good dreams :)

# 2025-10-06: SCHEMATICS ARE DONE. PCB HELL BEGINS.

## Milestone
* Started printing the lower part of the long shoulder module.
* Configuration of Altium for starting the PCB is over.
* Created all remaining components for the Axis Channel blade with their footprints.
* Imported all components into the PCB project.

## Current Status
- **Schematics:** Replaced all default Altium components with my own custom ones.
- **Libraries:** Built a complete library with every single component for the Axis Channel blade.
- **PCB:** The PCB file is created. The board outline is set to 100x100mm. The layer stack is defined. All components have been imported.

## Next Steps
- **PCB:** FINALLY START IT!!!!!
- **CAD:** Continue printing and assembling parts.
- **LTspice:** Run one or two more simulations for the LDOs.

## Comment

It's 3:40 AM on a Monday morning.... **[dying sounds]**

That was insane, really. So many hours creating footprints, hunting for datasheets, and fighting with Altium settings. But it's finally over. We are starting a new part of this strange story!

**AND for now!!!** <Have a good night, guys :)>

## 2025-10-13: PCB Hell might not BEGIN, but it could start this week...

### Milestone
* Finished printing the long lower part of the shoulder module.
* <I use Arch btw>...
* Completed simulations for the 12V, 8V, and 5V DC/DC converters.
* Corrected the DC/DC schematics in Altium and validated them in LTspice.

### Current Status
- **Printing:** The lower part of the shoulder module is done. The new support settings are working well.
- **LTspice:** Finished the DC/DC simulations and found a major problem in my original schematic. I'm not sure how it even worked before, but it's correct now. In short, I had issues with the feedback and COMP circuitry. It's fixed now.
- **Altium:** Corrected the Axis Channels chematic. I will start the PCB layout this week.
- **Arch:** Installed Arch Linux on my new laptop. I'll be using it for all STM programming and other development.

### Next Steps
- **PCB:** FINALLY START THE LAYOUT! ~~(This time for sure...)~~
- **CAD:** Print the upper part of the shoulder module.
- **Arch:** Finish configuring the development environment.

### Comment
This weekend was just tr... khm...

I forgot my laptop charger in another city, so the entire weekend was lost, and I literally did nothing. However, on Saturday, I received my new laptop ~~(a ThinkPad, running Arch btw)~~ which was the only good news.

I spent all of Saturday evening and all of Sunday installing Arch(~~on a ThinkPad, btw~~) and just finished it today.

Now I have the proper tool for thepost-PCBsteps. Today, I managed to fix the schematics and finalize the DC/DC simulations.

That was just some bad luck, and I hope it's the last bad weekend for a while ~~(nope)~~.

Thanks for your attention, <have a good night!> :)

# 2025-10-20: WE ARE BACK! 55% OF THE DRIVER IS DONE.

## Milestone
* Started printing the long upper part of the shoulder module.
* Completed the placement of all main power components (half-bridges, amplifiers, gate drivers).

## Current Status
- **Printing:** I've started printing the upper part of the shoulder module after making fixes to the CAD model.
- **Altium:** The Axis Channel schematic is fully corrected. This week, I'm diving deep into the PCB layout.

## Next Steps
- **PCB:** Finish component placement and begin the routing phase.
- **CAD:** Test assemble the long shoulder module and buy the 10mm shafts.

## Comment

This was just a very good weekend, and I can't comment on that any other way.

Everything I wanted to do, I did!

I spent all night on the placement of the MOSFETs, and along with them, I placed the amplifiers and gate drivers. And that's just... finally, it's done!!

`Just start the task.`
        `Just finish the task.`
                `That's how I will build this robot!`

<Have a good night, guys :)>

# 2025-10-21: Little Refactor

## Milestone
* Refactored the entire placement of the main power stage components. The primary goal was to drastically shorten the path from the gate drivers to the MOSFET gates.

## Comment
Before this refactoring, the trace length to the upper MOSFET's gate was around `~10mm`. After a complete re-layout of the power core, the new path is now only **`1.5mm - 1.8mm`**. This is a massive improvement that will significantly reduce gate loop inductance, leading to faster, cleaner switching and lower thermal losses.

# 2025-10-27: Placing is Over

## Milestone
* Finished placing the RS-485 receivers, the MCU-ADC, and the 5V DC/DC converter.
* Started printing the long upper part of the shoulder module... again...
* Tested new hole sizes for the pins in the 10:1 reducer.
* Dialed in new settings for Orca Slicer.

## Current Status
- **PCB:** I've finished placing 90% of the components. The last 10% are the two remaining DC/DC converters.
- **Printing:** This weekend's main theme. I broke the upper part of the shoulder module while trying to fit a bearing. After that, I changed my settings and printed a new stator, shaft, and outer flange. Then I started printing the upper part of the long shoulder module again. And, to top it off, I broke the lower part of the short module during assembly. It was a bad print from the start and was just defective all this time.

## Next Steps
- **PCB:** Finish component placement and begin the routing phase. ~~(Still same)~~
- **CAD:** Test assemble the long shoulder module and buy the 10mm shafts.

## Comment

Just an insane weekend. I finally finished the majority of the placement, and I think the routing will be easy because all the components are placed very close together, allowing me to use copper pours for many connections.

I broke TWO parts this weekend... AAAA... *khm*. But now I know that one of them was trash from the beginning, and the second one *can* fit the bearing, but only if you don't use a hammer...

A very good weekend. I hope the same for you :)

<Have a good night, sleep well guys>

# 2025-11-03: Little Necessary Work

## Milestone
*   Finished component placement for the Axis Channel blade.
*   Finished printing the long upper part of the shoulder module.

## Comment
Just some necessary work is done. Tomorrow, the plan is to finish the reducer assembly, start the PCB routing, and begin printing the lower part of the short shoulder module.

And now... <have a good night~>

# 2025-11-09: FINALLY, LAYOUT!

## Milestone
*   Replaced the MCU and its supporting components on the layout.
*   Completed the initial routing for the entire Top Layer of the Axis Channel blade (~50% of total routing).

## Current Status
- **PCB:** Literally what I said above, haha.
- **Printing:** The new head for the long shoulder module broke because the layers didn't merge properly. When I tried to press-fit a bearing (gently, really!), it just went *CRRRRR* and... *khm*. Anyway, I'll be reprinting this part (this will be the third try).

## Next Steps
- **PCB:** Finish routing!
- **CAD:** Print the head of the long shoulder module *again*, and finally `buy the 10mm shafts`.

## Comment

Phew... it's 4 AM again, and I'm sitting here, trying to make little steps to create this thing. I was a little sad when the shoulder module part just broke again, but then I tried pressing a bearing into the second hole, and it didn't break! It even held up while I was pressing it in, which gives me hope :).

I've also made a decision: first, I'll finish the routing, and *second*, I'll place the PCIe connector on the schematic. I need to understand where the routes can connect to the PCIe connector most efficiently to create the shortest paths, and only then will I finalize the connections on the main schematic.

After the part broke, I just took a hammer and smashed it to see how good the infill was. And honestly, it wasn't bad. Of course, it could be better, but it's a really solid plastic part. When I hit it, it just deformed, and only after about 10 hits did it shatter into small pieces. Yeah, some walls looked like they weren't solid, but maybe that's just the limit of 3D printing, because when I hit it, it reacted like a solid part.

So, yeah... I think it's time to sleep. <Have cool dreams~>

# 2025-11-10: Updated settings for Orca

## Current Status
- **Orca slicer** updated orca slicer settings

## Comment
U know what ?? `updated orca slicer settings!!` ~~(insane right?)~~

# 2025-11-16: Little Steps in Layout

## Milestone
*   Successfully assembled the head-shoulder module.
*   Learned all about vias. 
*   Made the layout for the GND and PWR planes.
*   Finally bought the 10mm shafts.

## Current Status
- **PCB:** I spent the entire day trying to figure out how to properly place vias for the GND and PWR planes, but now I finally know how to do it. And now, I need to go to sleep :(
- **Printing:** Finally pressed the bearings in without breaking the part! Now starting to print the base.

## Next Steps
- **PCB:** Finish routing the bottom side!
- **CAD:** Print the base.

## Comment
This weekend felt very short. I had to visit a lesson at the university this week, which is in another city, and by the time I got back, a day was gone.

So I only had one real day, and I spent all of it just understanding how to place vias correctly. For now, I need to go to sleep, but at least I know how to do it. I think the actual work of placing them will be pretty simple and fast now.

<have a good night guys ~>

# 2025-11-18: THE BEAST HAS A NERVOUS SYSTEM

## Milestone
* All signal paths are now routed.
* The "quiet" side of the board is essentially complete.

## Comment
I like how it's going. I think we can do it.

<Have a good night, guys. We're almost there.>

# 2025-11-24: LAYOUT - OVER.

## Milestone
*   **PCB:** Finished the PCB Layout / Routing.
*   **Mechanics:** Tested the new connection mechanism between reducer stages (Success).
*   **Printing:** Started printing the stator for the rotary support.

## Current Status
-   **PCB:** Yeah, we did it. The next step is a final error check (DRC), ordering the boards, and then... the scary part: Programming.
-   **Printing:** The base wasn't printed because the extruder got stuck/clogged. But I did some thinking... why spend 5kg of plastic on a base that will still be lightweight? I decided to use a **cheap, heavy concrete block** instead.
    *   Started printing the rotary support (had to cut angles slightly to fit the print bed).
    *   Spent 4 hours fixing the jammed extruder. Learned a lesson: after cleaning plastic and reassembling, you need to give the printer time to "chill," or the thermal sensor won't work right.
-   **CAD:** Designed a new mechanism to connect the two reducer stages. I made vertical slots for steel pins in the shaft, slots in the outer flange, and an 8mm plastic pin in the center for alignment. It's perfectly centered now.

## Next Steps
-   **PCB:** Order the boards!
-   **CAD:** Print the rotor for the rotary support.

## Comment
Okay, I can only sleep 4 hours again, but I finished the layout and wrote this log.

The next stage — Programming — is coming, and it's a little scary because the other stuff isn't fully finished. Drivers need to be ordered, mechanics aren't fully printed... but we need to go down this road. We can't stay still — that is the main rule.

The order itself is a challenge. Waiting 1 month... for what? To potentially see fire from my board and then wait 1 month again? It's a risk, but I knew these nuances from the start. I understand them.

If it really works... I can't imagine how happy I will be.
And next month — exams. That's also a challenge.
So, conditions are not friendly. But when were they ever? :)

We broke through it.
<Have a good night, sleep well guys>

# 2025-12-19: ALIVE!.. Maybe Alive...

## Milestone
*   Gerber, BOM, and CPL files for the Axis Channel blade are generated and ready for production.
*   The 3D printer's hotend has been replaced; printing has resumed (after a month of waiting).
*   Fixed the main problem with the reducer.
*   `components.md` has been refactored into a more structured format.

## Current Status
-   **PCB:** Waiting for the "go" signal from my contact to place the board order. The logistics are complicated, so this is currently on hold.
-   **Firmware:** The lab bench is set up. I have a dev board for motor control, the STM32H7A3 dev board, a Tang Nano FPGA board, three BLDC motors, optical and magnetic encoders, a lab PSU, and a ton of wires. The goal for this month is to get the core firmware up and running.
-   **Printing:** The new hotend is installed. Tried to print the massive slew drive. The part is warping and lifting, but I will fix it. I think it's bad settings or G-code, but I'll probably need to build an enclosure for the printer anyway...
-   **Documentation:** I completely rebuilt `components.md`. The old "just throw it in" style was great for brainstorming but terrible for actual work and comparison. The new version is structured and much more usable.

## Next Steps
-   **Firmware:** Start writing and debugging the core firmware on the dev boards.
-   **PCB:** Push for the board order.
-   **CAD:** Successfully print the slew drive and the reducer parts.

## Comment
It feels like a whole month just vanished. The last commit was on November 24th...

Between work getting intense (late nights, releases) and university exams hitting hard, the robot had to take a backseat. I spent days that should have been for studying on generating production files, and now... waiting for logistics.

It's frustrating. While the boards are in limbo, I need to finish my exams and, on my free days, start the firmware. I have everything I need to start writing and testing the code. By the time the real hardware arrives, the firmware should be 80% ready.

Just sorry for this month... ~~it will happen again.~~

<Have a good night, guys. The fight continues.>

# 2025-12-24: General Kenobi!

## Milestone
*   Updated components.md.
*   Successfully printed the slew drive.

## Comment
You know how I'll name the next dev log... *khm*.

This month was dominated by exams, and I just couldn't work on the robot full-time. But now, with the last exam of the year on Dec 26th and the next one not until Jan 11th, I'll have plenty of time to develop the firmware.

The guy who's ordering my boards says he's ready to try and place the order in the coming days.

Printing is going well, too! I made a cardboard enclosure for my printer, and the slew drive was successfully printed with new, faster settings.

It was a hard month, but now I believe it's over, or at least it's giving me a little break. Anyway, we are reaching the middle point of the project!

Thanks for your attention :)

<Good night, guys :))>

# 2026-01-03: Hello there!

## Milestone
*   **FPGA Core:** Successfully completed ~80% of the FPGA code.
*   **CAD:** Started printing the final version of the reducer.~~(and fixed the printer)~~

## Current Status
-   **Firmware:** Written the modular architecture in SystemVerilog.
    - `system_storage`: The CSR brain of the axis.
    - `pwm_generator`: Center-aligned PWM for FOC.
    - `deadtime`: Hardware protection for MOSFETs.
    - `quadrature_decoder`: Glitch-filtered encoder reading.
    
    *Key Discovery:* Spent some time fighting with the encoder signal. Turns out the Omron encoder with Open Collector output needs strong external pull-up resistors to 3.3V. Once added, the FPGA saw the signal instantly.

-   **CAD:** 
    -   **Upgrade:** Installed a new PEI build plate.
    -   **Repair:** Fixed critical mechanical play in the printer. It turns out the toolhead was misaligned due to an assembly error. I tightened all the V-wheels, and now everything is working fine.

## Next Steps
-   **Firmware:** Connect the PWM output to the real gate driver and finalize the FPGA core.
-   **PCB:** Push for the board order.
-   **CAD:** Finish printing reducer parts and start printing the rotor for the slew drive.

## Comment
It's 2:00 AM.

Sleep is.. what is this.. khm..

FPGA is very interesting, very strong, very fast AND!! very scary!!

Honestly, I just can't understand it sometimes... **Assembler feels easier!!!**

But after two days of trying to decipher these hieroglyphs, I finally started to understand, and to be honest — it's simple. On an STM32, you have a thousand functions with strange names and you need to know them all. But on an FPGA, you just have logic gates that haven't changed in the last 100 years. It feels like playing chess for the first time.

As for CAD, I'm so glad for the new PEI plate. The adhesion is insane — I actually need to heat the plate just to remove PETG parts. 

I also fixed the backlash today. Spent 3 hours on it because I had to disassemble the entire printer, reassemble it, realize I missed something, disassemble it again... aaaaand finally assembled it right.

<Have aaaa very good night guys :) Happy holidays!>

# 2026-01-06: FPGA CORE COMPLETE!

## Milestone
*   **FPGA Core:** Successfully completed the FPGA core architecture.
*   **CAD:** Printed and assembled the final version of the reducer!!!
*   **PCB:** Boards are ordered.

## Current Status
-   **Firmware:** All FPGA modules are written and verified. The FPGA is ready to connect to the MCU and drivers to spin the motor! But... this also means I now need to write the code for the MCU.
-   **CAD:** I assembled the reducer and it works!! It's a little tight (I will adjust tolerances in the next iteration), but... **GUYS, IT'S A 100:1 RATIO, IT FITS IN THE PALM OF MY HAND, AND IT WORKS!**
-   **PCB:** Boards are finally ordered! In about two weeks, we'll see the Moment of Truth (and hopefully no magic smoke).

## Next Steps
-   **Firmware:** Develop the MCU firmware and connect the PWM output to the real gate driver.
-   **CAD:** Refine reducer tolerances, start printing the rotary support, and update the CAD models.

## Comment

You know what time it is? 2:00 AM! Again!

But I'm just happy because I'm done with the FPGA part and can finally move to the next step of making this robot alive. ^^

<Have a goooood night!>

# 2026-02-08: ADC 400ns without CPU!

## Milestone
*   **FPGA Core:** Updated code to test the new ADC setup and adjusted delays.
*   **CAD:** Successfully printed the rotary support and performed a test assembly.
*   **MCU:** Implemented a bare-metal, zero-CPU-overhead Dual ADC-to-SPI Data Pipeline.

## Current Status
-   **Firmware:** The FPGA core is ready and waiting for the other parts of the system. I've tested the new ADC setup with it, and it works! Latency is projected to be around **400 ns**.
-   **CAD:** I fought with the printer all month for just two parts, but the rotary support is finally finished. I think I've learned all its quirks. (If you really try to build this, I hope you buy a better printer, but my goal is to prove you can make my robot on ANY printer).
-   **PCB:** Still waiting ;-; .

## Next Steps
-   **Firmware:** Make the motor spin using the full chain: ADC -> FPGA -> STM32H7. Maybe even start on FOC.
-   **CAD:** Update the model for the Shoulder_Clevis_Mount and figure out how to print this monster. I think it will eat more than 1kg of PETG.

## Comment

You know what? I can't believe a whole month just passed. I spent almost all of it trying to print, but this printer just didn't want to cooperate. I spent a huge part of my time just trying to understand what I was doing wrong. Two recommendations: 1. Wash your build plate (really, it's insane how well it works). 2. Don't buy an End... *khm*. Change your Z-offset while the printer is printing the first layer, and if it doesn't stick, make the gap smaller.

And the whole month I was fighting with the ADC. I tried to configure it so that when the ADC sends data to SPI, a leg of the MCU would catch it and raise a logic level. But the first week ended with zero results. The second week, I actually made it work, but the gap between the data and the logic signal was **20 µs**. I can't find the words to describe how sad it was to see that. After a whole weekend, I got it down to **6 µs**. A good result in comparison, but VERY, VERY bad for my goal. I need the data after 1-2 µs max; 0.5 µs would be perfect, leaving me 9.5 or 19.5 µs for the other things in the FOC cycle.

I don't know what I was doing in the third week, maybe I just deleted all my SPI and ADC code. But last week, I just sat on it after work and study, like 6 hours a day until 2 AM. And this Friday morning, I finished it. I can see that my ADC is working! It's just unbelievable. And now I've polished the code and even made a Makefile (ha-ha) for easy use later.

Sorry for the long pause, guys!

<HAVEEEEE AAAA GOOOOOOOOOOOOOOOD night :> >

# 2026-02-12: Architecture Document 

### Milestone
*   **docs:** Created `architecture.md` — full system architecture document.
*   **CAD:** Strarted printing shoulder clevis mount (cabin) and it`s eat 970 gr PETG with 80% fill (im happy).

### Comment
2:33 AM. Classic.

many bla bla bla but it is necessary

<Have a good night ~>

# 2026-03-12: The Beginning of the End

## Milestone
*   **FPGA Core:** Finished `top.sv` for FOC, encoder, and ADC. Full system integration complete.
*   **MCU:** Finished FOC implementation and integrated it into the complete system.
*   **CAD:** Printed the last main structural part.
*   **PCB:** Boards are VERY NEAR.

## Current Status
-   **Firmware:** All parts are working together as one system. **My architecture is correct.** On dupont wires, I achieved 20 kHz FOC. The full real-time chain works end-to-end: FPGA reads encoders and ADC currents from G4, packs them into a 256-bit SPI frame, sends to the H7, the H7 runs FOC and sends PWM commands back — all at 20 kHz, on a pile of dupont wires.
-   **CAD:** The shoulder clevis mount is printed. We now have all the parts to start assembling the body of this plastic hero.
-   **PCB:** Boards are coming to my house around March 20th. ~~hope they will work~~

## Next Steps
-   **Firmware:** Freeze while assembling the body.
-   **CAD:** Start assembling all parts of the robot and polish the fit of each piece.

## Comment

We have come to the end of this work, and we will end this at any cost.

I can't get used to the fact that every new step with electronics and code is a month of work. And I really do work on it — sitting for hours, two or more nights a week until 4 or 5 AM, trying, trying, trying again and again. And the funniest part? Not understanding what isn't working. Is it the code? A dupont wire? Did I assemble the circuit wrong? Maybe the encoder is on the wrong side? That uncertainty is the hardest part of all of this.

**But anyway, like everything else, it just needs time. And what can stop me now? Huh?**

**The firmware part is over!**

Let's just remember what I wanted to finish from the start: CAD, PCB, and... firmware. Now we just need to make it all work together. We have all the parts for it.

**Time to finish this.**

**AND NOOOWW..** time to go to sleep.

<Have a good night, good person! :> >

# **2026-04-24: Yep, it's me again. And I'm not dead.**

## Milestone
*   **Docs:** Fixed the `architecture.md` file.
*   **CAD:** Repaired the printer and printed the 60-tooth rollers; designed a motor holder; assembled the shoulder modules; printed and adjusted the actuator module; fixed the reducer models; developed a new 20:1 reducer and ordered materials for it; and finally, assembled and tested the rotary support.
*   **PCB:** Tested all board systems (they work!) and updated the Gerber files.

## Current Status
*   **CAD:** It's been a sea of troubles, but I managed to get everything I listed above done.
*   **PCB:** THE BOARDS WORK! ...well, with one tiny issue. I accidentally shorted a trace under a suppressor in the third half-bridge. A quick fix later, and everything is running smoothly. I've tested the DC/DC converters, spun a motor, and successfully programmed the microcontroller. The Gerbers are updated with the fix, so if you're brave enough, you can order them now.
*   **Docs:** I accidentally deleted the old architecture file. When I finally noticed, I just fixed it. No further comments.

## Next Steps
*   **CAD:** Keep assembling all the parts.
*   **Docs:** Write my thesis.

## Comment
This past month hasn't been the most exciting, I'll admit. There were no major milestone breakthroughs—just a whole lot of grinding. I've been assembling, printing, writing my thesis, and fixing one small issue after another. Sorry for the radio silence on GitHub, but I honestly didn't know what to write. It's not that things are bad, just that it's been a ton of little tasks—all hands-on work, spending money on bearings, shafts, and other hardware.

One interesting discovery: trimmer shafts. They're incredibly cheap, strong enough for the roller bearings, and conveniently 8mm in diameter.

A huge amount of time went into printing. I think the next dev log will be after I'm done with my thesis. If you want to see what I'm up to in the meantime, you can follow my Telegram channel.

Thanks for your attention. **The work doesn't stop.**

<Have a good night>

# 2026-03-12: First axis assembled (almost)

## Milestone
*   **Assembling:** First axis assembly is almost complete.
*   **Base:** Finished the epoxy granite base and uploaded the casting guide.

## Current Status
-   **Assembling:** 2 reducers and the rotary support are fully assembled. Currently trying to screw on the clevis mount.
-   **Base:** hmm... what did I do... forgot..

## Next Steps
-   **Assembling:** Assemble the second axis.
-   **CAD:** Continue assembling all the parts of the robot and polish the fit of each piece.

## Comment

I made the base out of epoxy granite, and it felt like doing stonemason work all day. My room looks like a dump again. I have a ton of parts laying around, I need to assemble them, buy more embedded screws, aaaaand!!! that's it. 

It took a lot of time to build the two reducers, but thankfully they work on the first try! Maybe not perfectly yet, but they work. 

Just a few last steps and the robot will come alive in this very, very positive world... I think its first words will be "why me".

First commit that's not at 4 AM... huh.. <Have a good day guys!>

# 2026-07-05: That was a long way

## Milestone
*   **Assembling:** Second axis assembled and tested.
*   **CAD:** Developed encoder holders for the first 3 real axes.

## Current Status
-   **Assembling:** Reducers for the 2nd and 3rd axes are assembled. The 2nd axis was successfully tested with a 10kg load (or 25Nm) and is now fully assembled.
-   **CAD:** Finished the design of the 3 encoder holders for axes 1, 2, and 3.

## Next Steps
-   **Assembling:** Assemble the final axis.
-   **CAD / CNC:** Start developing the 500W CNC module.
-   **Firmware:** Start developing the main control loop and inverse kinematics.

## Comment

That was an interesting experience. Really. This past year was hard. The milestone idea for this project was born last May, and looking back at it now, I just think: "Is a whole year really gone?.." And the robot still isn't finished. It's a little sad, and my ego is slightly hurt, but let's look at the bigger picture.

What did I have when this story started (and it's not over in this moment :) )? 

Last year, all I knew was that the LM358 is a good chip... and that's it. You want to ask about mechanics? Good question... nothing. I knew nothing about mechanics. Maybe code? Again, no. Just 4 Arduino lessons, and honestly, I didn't understand a single word of the code when I started.

I just said: "I'm going to build a robot, and to hell with the difficulties, I'll make it anyway!" 

Why did I say that? <I don't know if you're asking this, but I'll answer anyway -^-> 
Because everyone tells you "it's just a diploma," "it's just university," "maybe you can do it, maybe you can't, it doesn't matter." But I saw how others are building this world, and they aren't building the world I want to live in. Maybe those are big words for me, but it's true. Along the way, I just focused on giving it everything I could. Maybe it won't work in the future, maybe I'll stop the project, but this is my answer to everyone who thought I couldn't do what I wanted. 

Why this monologue? To say this: If you think you can't do something, remember me. Tell yourself: "If this guy could do all of this from scratch, I can do whatever I believe in." 

If you don't want to do something, that's normal. I wouldn't do anything either, but I have a paranoid head and I just go out of my mind if I stop working :>

Now, I am a Lead Embedded Engineer (it's my third day!), and this month I won't be able to physically assemble the robot, but I plan to start on the main loop and inverse kinematics and upload them to Git.

Sorry for the 2 months of silence. I had to chill and write my diploma. I already defended it, and next week I'm just going to pick it up! Then I can finally say I'm done with university. And now I work in the capital of my country.

That was an incredible experience. I just hope the world doesn't end in the next year so I can finish my robot and you can watch this development! 

<Have a hell of a good day!>

# 2026-07-12: free weekend

## Milestone
*   **Firmware:** Wrote the main part of the upper control loop.

## Current Status
-   **Firmware:** I now have the main part of the upper loop: inverse kinematics, the servo code, the trajectory planner, and hardware sin/cos on the FPU. It's written and the math checks out, but it isn't compiled or wired into the running cascade yet.

## Next Steps
-   **Firmware:** Test it and finish the whole upper control loop.
-   **Assembling:** Assemble the final axis.
-   **CAD / CNC:** Start developing the 500W CNC module.

## Comment

Keep developing, keep working!

and <Havee a goood niiight :> >

# 2026-08-02: Work, hard work

## Milestone
*   **CAD / CNC:** Selected an 800W spindle and created a CAD model for the adapter.

## Current Status
-   **CAD / CNC:** Upgraded the spindle choice for the CNC module to 800W (up from 500W). Found a blueprint for the spindle holder and designed the CAD model for the adapter.

## Next Steps
-   **Firmware:** Test it and finish the entire upper control loop.
-   **Assembling:** Assemble the final axis.
-   **CNC Hardware:** Choose an MCU to control the spindle and communicate with the robot. Select a motor driver for it.
-   **CNC Firmware:** Order the remaining parts for the CNC system and write the control/communication code to interface with the robot.

## Comment

Because of work, I can't go home to grab my robot, and I have to work all week. I really hope this first adjustment phase and the first month of my new job wrap up soon so I can finally get back to thinking about my project. If not, I hope things settle down soon anyway. I like my new job, but the robot and the CNC module remain my top goals. Thanks to everyone who is still following along! :)

And what? Have a... Good... What? <Night!>

# 2026-08-04: Work, hard work *upd!*

## Milestone
*   **CNC Hardware:** Selected the CNC kit and an ESP32-S3 for the CNC module.

## Current Status
-   **CAD / CNC:** I selected a kit from AliExpress with a pump, VFD, spindle, and spindle holder (around $100), as well as the MCU. The MCU is an ESP32-S3-N16R8, and I chose a TTL-to-RS485 module for communication.

## Next Steps
-   **Firmware:** Test it and finish the entire upper control loop.
-   **Assembling:** Assemble the final axis.
~~- CNC Hardware: Choose an MCU to control the spindle and communicate with the robot. Select a motor driver for it.~~
-   **CNC Firmware:** Order the remaining parts for the CNC system and write the control/communication code to interface with the robot.

## Comment

Trying out a quick style update for the dev log, as I didn't want to create a whole new file with a long title just for a short text.

<Have a good night> I'll order everything once I get paid!... though it'll take about a month to get here... yee....

# 2026-10-08: S*t happens

## Milestone
*   **CNC:** Add architecture of cnc for esp.

## Current Status
-   **CAD / CNC:** All on my board and i add all files for start make it alive.

## Next Steps
-   **Firmware:** Test it and finish the entire upper control loop.
-   **Assembling:** Assemble the final axis.
-   **CNC Firmware:** ~~Order the remaining parts for the CNC system and~~ write the control/communication code to interface with the robot.

## Comment

No comments so many GOAT live events with GOAT trash events on every week, mb i start be bad for this... but i dont stop disgrace yourself!

<gooood night have guys!>

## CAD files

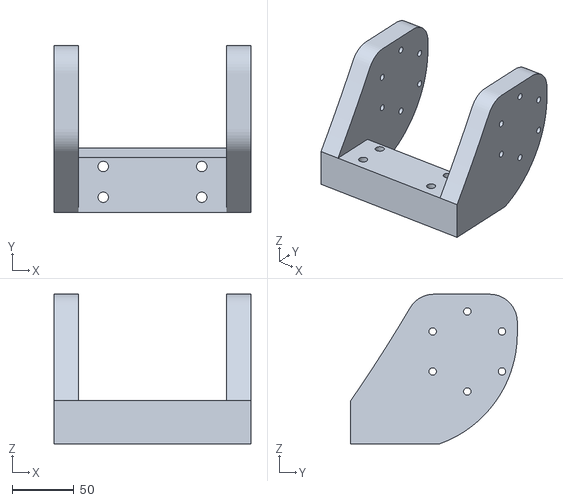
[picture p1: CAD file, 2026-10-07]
cad/manufacturing/stl/Modules/adapter_for_holder_spindle_65mm.stl
160.0 x 135.4 x 121.5

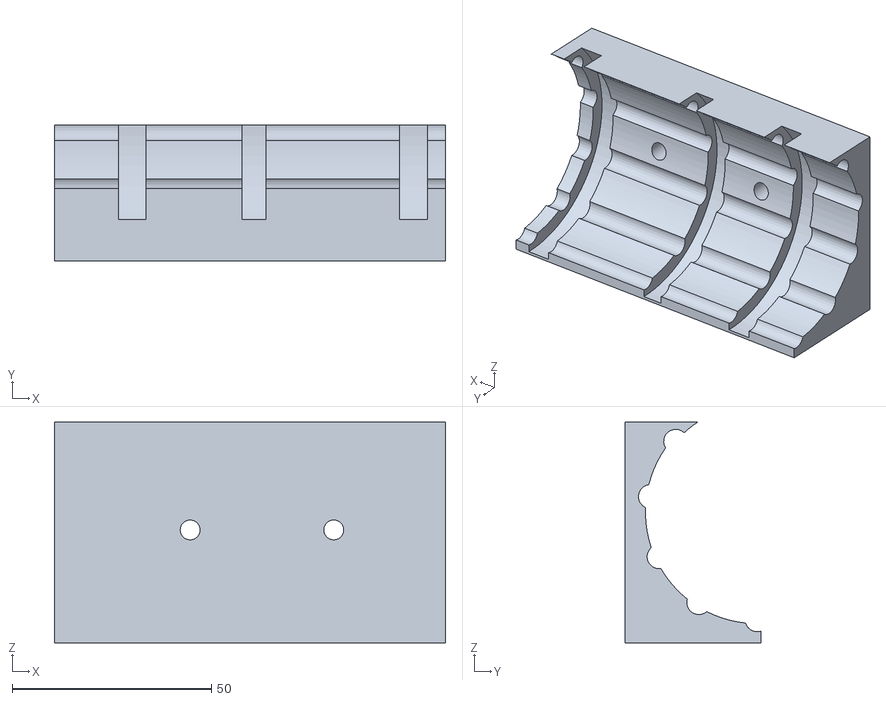
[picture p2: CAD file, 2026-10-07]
cad/manufacturing/stl/RIGEL/Actuator_module/reducer_holder.stl
98.0 x 34.2 x 55.3

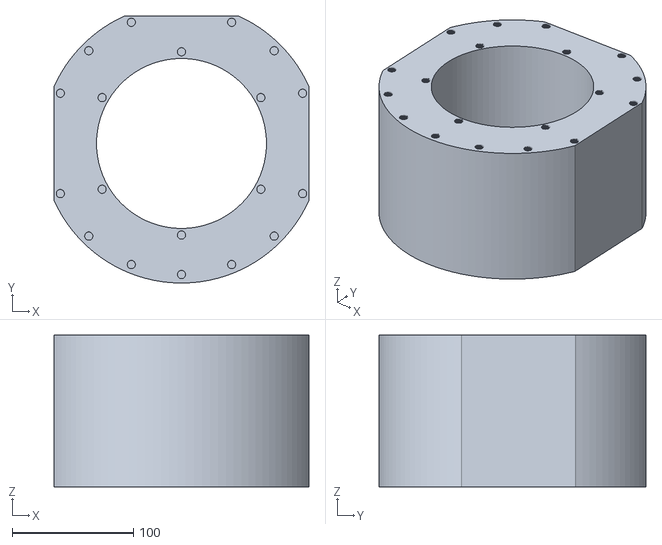
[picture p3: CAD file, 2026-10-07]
cad/manufacturing/stl/RIGEL/Base/Base_V_1_2_.stl
210.0 x 219.9 x 125.0

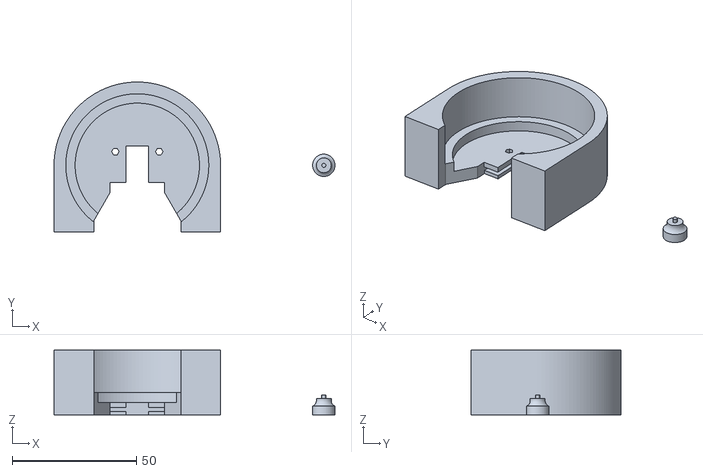
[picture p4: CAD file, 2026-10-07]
cad/manufacturing/stl/RIGEL/hat_for_motor/hat_for_motor_v1.5.stl
113.0 x 60.3 x 26.0

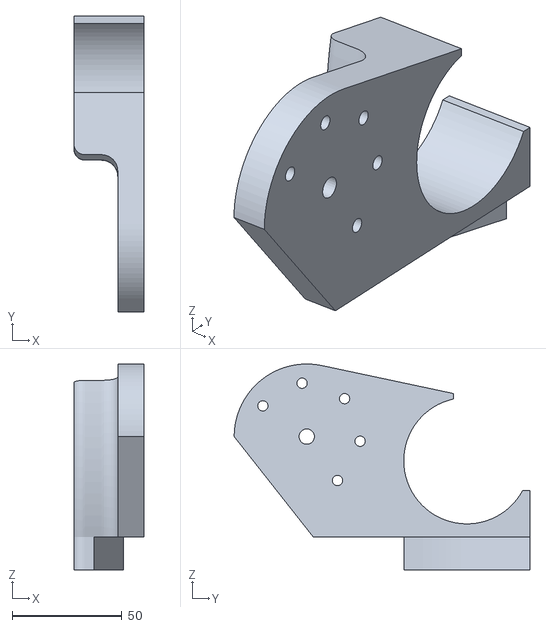
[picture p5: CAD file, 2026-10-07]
cad/manufacturing/stl/RIGEL/motor_holder/motor_holder_clevis.stl
32.0 x 134.8 x 93.9

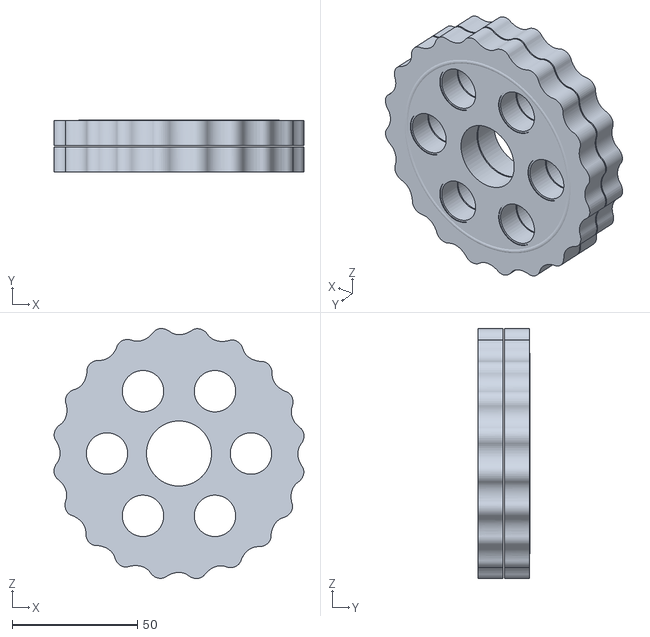
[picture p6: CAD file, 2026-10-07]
cad/manufacturing/stl/RIGEL/Reducers/20to1/20to1_reducer_v1.4.stl
99.9 x 20.7 x 99.9

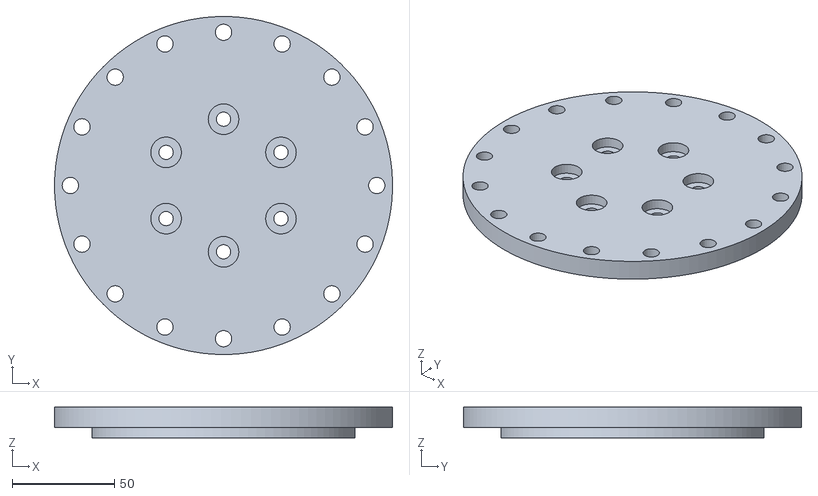
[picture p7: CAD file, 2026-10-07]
cad/manufacturing/stl/RIGEL/Reducers/Adapter/adapter_rtry_sprt_clevis.stl
165.5 x 165.5 x 15.0

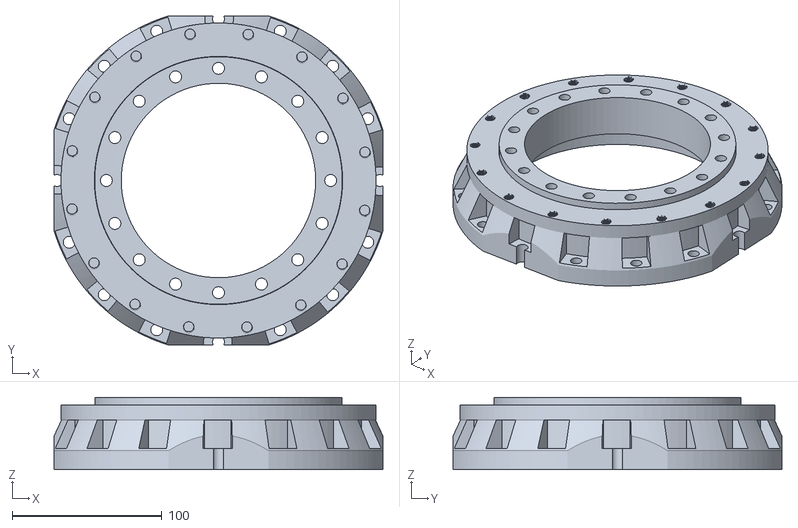
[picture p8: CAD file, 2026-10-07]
cad/manufacturing/stl/RIGEL/Rotary_support/Rotary support_V1.2.stl
220.0 x 220.0 x 48.2

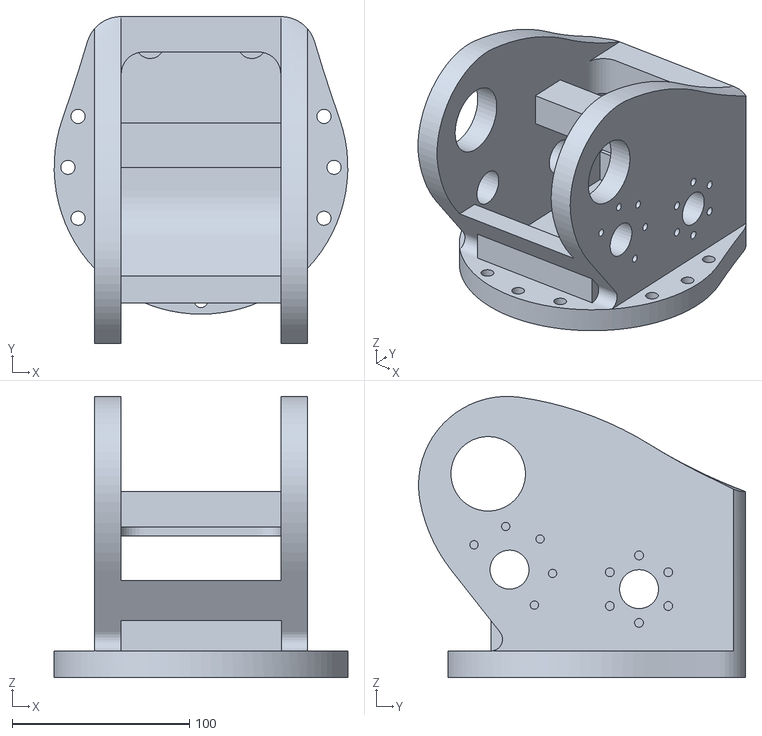
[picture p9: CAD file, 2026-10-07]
cad/manufacturing/stl/RIGEL/Shoulder_Clevis_Mount/Shoulder_Clevis_Mount_V1.3_.stl
165.4 x 184.3 x 158.4

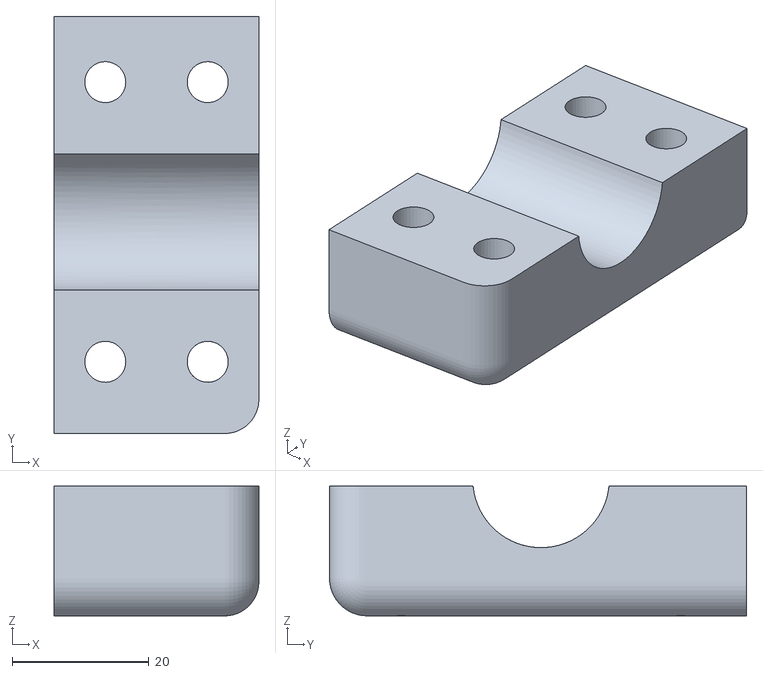
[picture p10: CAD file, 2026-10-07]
cad/manufacturing/stl/RIGEL/Shoulder_module_long/Right_ear_V1.1.stl
30.0 x 61.1 x 19.0

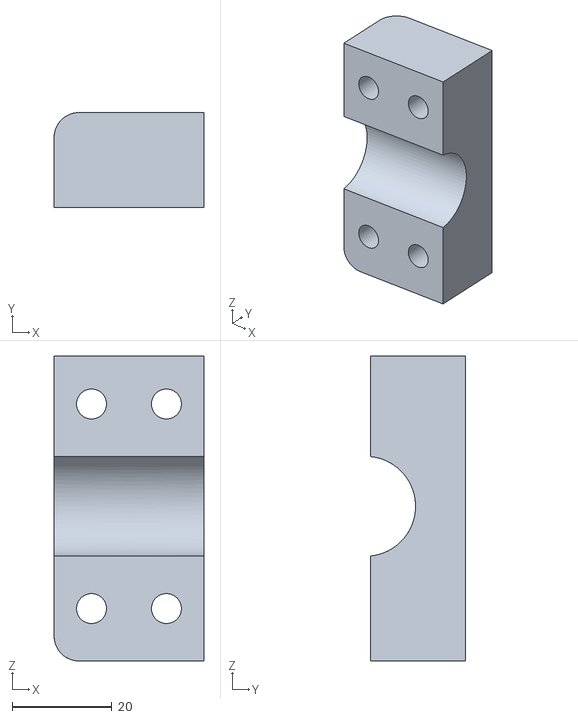
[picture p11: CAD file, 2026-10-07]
cad/manufacturing/stl/RIGEL/Shoulder_module_short/Right_ear.stl
30.0 x 19.0 x 61.1

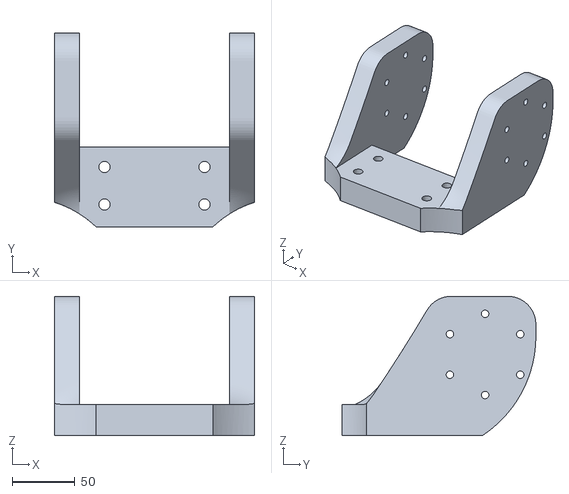
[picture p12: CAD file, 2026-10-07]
cad/manufacturing/stl/Modules/adapter_for_holder_spindle_65mm_V1.1.stl
160.0 x 155.0 x 111.5

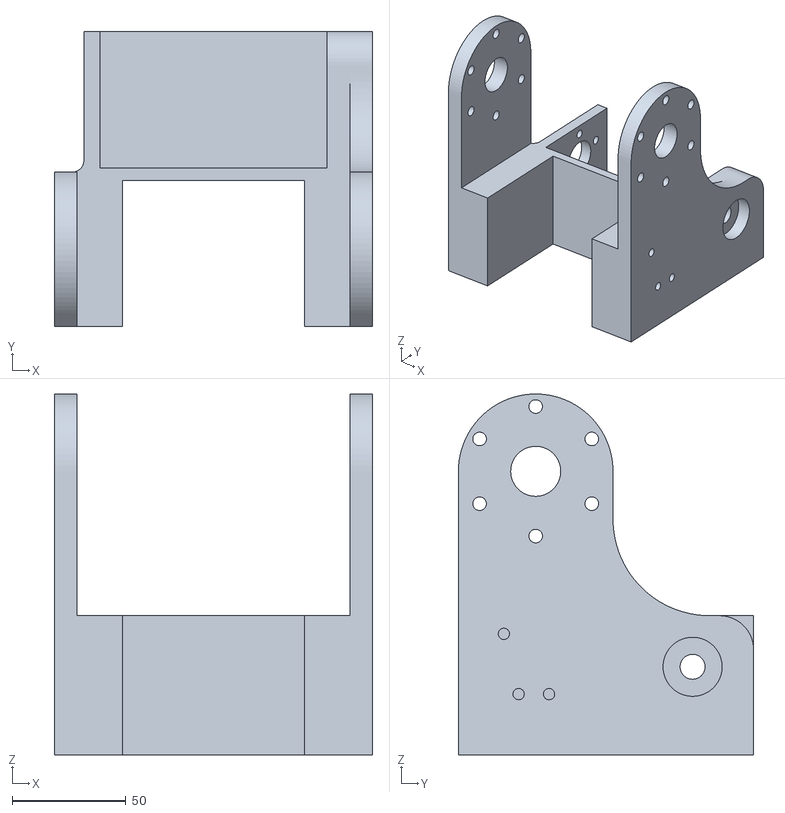
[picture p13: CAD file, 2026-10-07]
cad/manufacturing/stl/RIGEL/Actuator_module/Actuator_module_V1.1.stl
140.0 x 129.8 x 158.8

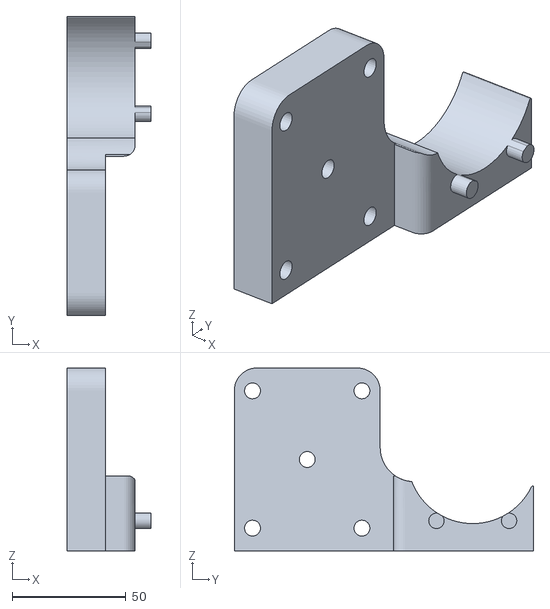
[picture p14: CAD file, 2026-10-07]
cad/manufacturing/stl/RIGEL/motor_holder/motor_holder.stl
37.1 x 131.8 x 80.6

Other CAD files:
cad/manufacturing/stl/RIGEL/Reducers/20to1/final_20_1_fastdisk_1.1.stl
cad/manufacturing/stl/RIGEL/Reducers/Adapter/adapter_V1.stl
cad/manufacturing/stl/RIGEL/Shoulder_Clevis_Mount/wheel_60.stl
cad/manufacturing/stl/RIGEL/Shoulder_module_long/Left_ear_V1.1.stl
cad/manufacturing/stl/RIGEL/Actuator_module/Actuator_module_part.stl
cad/manufacturing/stl/RIGEL/Reducers/Adapter/adapter_V1.1_8mm.stl
cad/manufacturing/stl/RIGEL/Reducers/Adapter/adapter_rotary_reducer_.stl
cad/manufacturing/stl/RIGEL/Reducers/Adapter/adapter_rotary_reducer_V1.1.stl
cad/manufacturing/stl/RIGEL/Shoulder_Clevis_Mount/Shoulder_Clevis_Mount_V1.3_part.stl
cad/manufacturing/stl/RIGEL/Shoulder_Clevis_Mount/stator_holder.stl
cad/manufacturing/stl/RIGEL/Shoulder_module_long/Body_of_1shoulder_module_V1.1.stl
cad/manufacturing/stl/RIGEL/Shoulder_module_long/Body_of_1shoulder_module_V1.2_down.stl
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

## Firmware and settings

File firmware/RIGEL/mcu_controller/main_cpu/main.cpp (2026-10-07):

#include "stm32h7xx.h"
#include "4_driver/stm32h7a3zit6_Q/hw_impl.h"

// These functions are implemented in C source files, so they need
// extern "C" linkage when called from a C++ translation unit.
extern "C" void hw_binding_init(void);  // Initializes all MCU peripherals (rcc, gpio, tim6, spi)
extern "C" void foc_init(void);         // Initializes FOC PI controllers and current references

int main(void) {
    // Set the vector table address to the start of Flash.
    // Required when using a bootloader or when the default VTOR doesn't
    // point to the application's vector table.
    SCB->VTOR = 0x08000000;

    // Initialize all hardware peripherals in the correct dependency order:
    //   rcc_init()       → clock tree (280 MHz)
    //   gpio_init()      → diagnostic LED pins
    //   tim6_init()      → microsecond delay timer
    //   spi_slave_init() → SPI3 + DMA + EXTI4 interrupt
    hw_binding_init();

    // Initialize the FOC current-loop PI controllers (zero integrators, set gains)
    foc_init();

    // Enable global interrupts — the EXTI4 ISR will now fire on every
    // SPI CS edge from the FPGA (~20 kHz), running the entire FOC pipeline.
    __enable_irq();

    // Main loop: all real-time work happens inside EXTI4_IRQHandler.
    // The CPU sleeps between interrupts to save power; WFI (Wait For Interrupt)
    // halts the core until the next interrupt arrives.
    while (1) {
        __WFI();  // Sleep until the next EXTI4 (or any other) interrupt
    }
}
